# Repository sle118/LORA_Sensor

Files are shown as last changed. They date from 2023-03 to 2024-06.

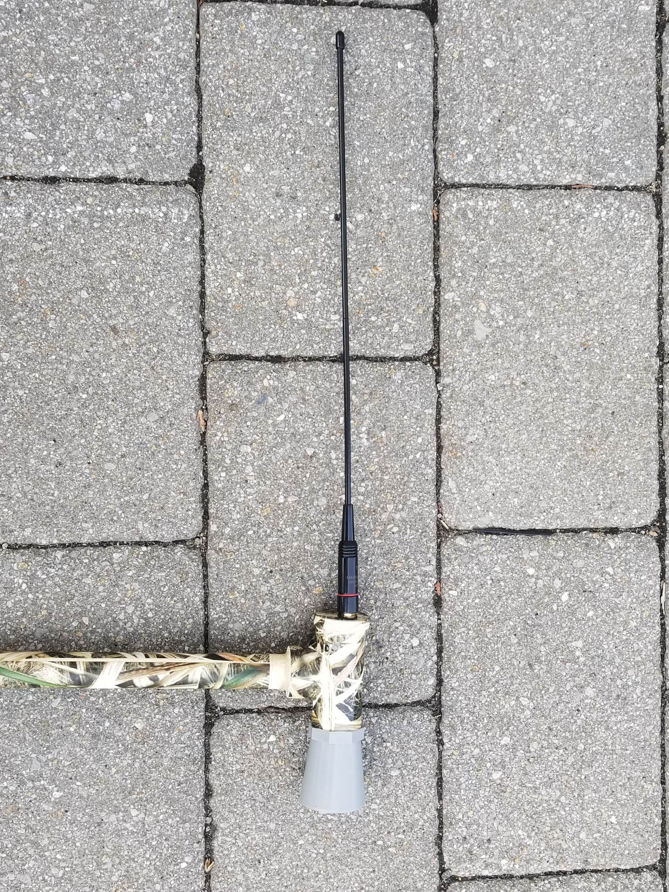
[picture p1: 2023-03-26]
LORA_sensor.jpg

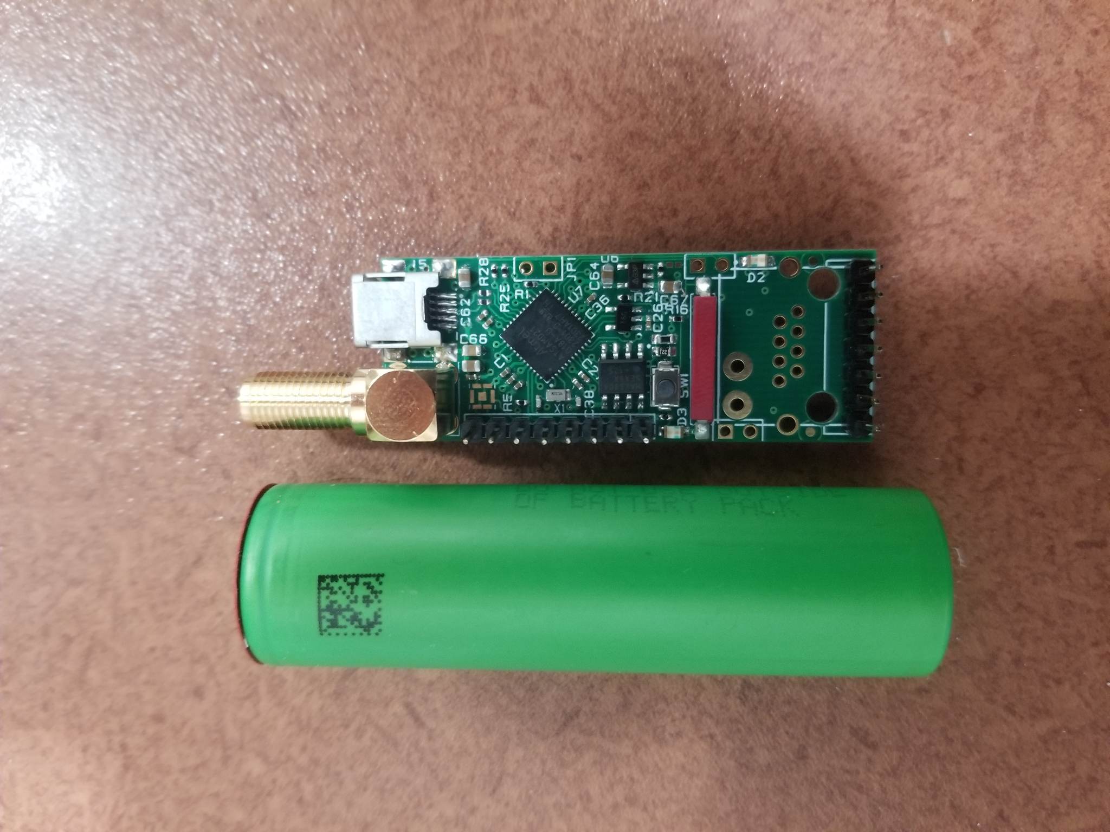
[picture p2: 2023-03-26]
transmitter/333065999_787963605601215_1816039696866618922_n.jpg

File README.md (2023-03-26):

river water level monitoring via long range wireless sensor (LORA) and send update every 15 minute

i made this project for monitor the river near my house that suject to some flooding
sensor is desin to be small and fit inside PVC "T" and have long battery live
 great versatility and hackability

1-)based arond SAMD21G17 CPU and arduino commpatible

2-)long range LORA FCC certified radio module (up to 10KM)

3-)over 60 day on a singel 18650 3.6V litium cell (optional solar charger)

4-)mesure up to 10meter whit 1cm accuracy or 5meter whit 1mm accuracy

5-)magetic reed switch for detection of ice covert melt

6-)barometric presure and temperature sensor

7-)provision for water level and temperature detection via sumerged sensor

8-)provision for turbidity sensor

9-)RS-485 for add custom sensor

10-)user programable GPIO

all this in 51.68 mm * 19.94 mm

main water level detection is via Maxbotic ultrasonic sensor or china clone

submerged water level is via LPS28DFW   1meter water = 9.78kPa or 1.42PSI

ice melt is via a simple rock on the ice the tie to a magnet via a fish line

when ice melt rock shink and pull the magmet so it trig the magmetic reed switch

a provision is made on the PCB for put sensor power OFF when magnet is present for keep battery live over the winter

solar charger is in developmemt and come soon

same for turbidity sensor , by use of low-cost dish-washer sensor

receiver side is adafruit Adafruit Feather 32u4 RFM95 LoRa Radio- 868 or 915 MHz
combined to Adafruit Feather HUZZAH with ESP8266 
both board is stacked whit GND and USB pin connected togeter
TX pin of Feather 32u4 go to RX pin of Feather HUZZAH

server side is plain web service hosting whit a FTP server  ,create a dedicated FTP accont on a WWW accesible folder  and copy the .php file to it

live exemple :

http://www.alphatronique.com/lora_sensor/mesure.php    <- real time sensor value

http://www.alphatronique.com/lora_sensor/donnes.txt    <- sensor data history

have copmlet assembled and tested PCB aviable please contack me via www.alphatronique.com

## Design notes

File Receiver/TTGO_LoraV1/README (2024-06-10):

# LoRa Receiver Arduino Project

This project implements a LoRa receiver using an ESP32 module to receive data from a LoRa transmitter and log it to a Google Spreadsheet via a deployed Google Apps Script web app. The code uses a combination of libraries and custom configurations to manage the network connection and data processing.

## Prerequisites

- **Arduino IDE**: Ensure you have the latest version of Arduino IDE installed.
- **ESP32 Board Package**: Install the ESP32 board package in the Arduino IDE (via Board Manager), using version 2.x.x. If your receiver board has a 40MHz crystal, then only you can use V3.x.x.
- **Libraries**: The following libraries need to be installed from the Arduino Library Manager:
  - `Adafruit_GFX` by Adafruit
  - `Adafruit_SSD1306` by Adafruit
  - `ArduinoJson` by Benoit Blanchon
  - `RadioHead` by Mike McCauley - as of writing this, only the ESP32 board V2.x.x is supported
  - `WiFiManager` by tzapu
  - `LoRa Serialization` by Joscha Feth 

## Folder Structure

Ensure that the folder structure from the GitHub repository is preserved as the project uses common definitions and configuration header files (`Definitions.h`, `Configuration.h`) shared between the transmitter and receiver. This is crucial for aligning data and radio correctly across both the transmitter and receiver.

### Setting Up Symbolic Links

If the symlinks are not already set up or are not properly propagated after cloning the repository, follow these steps to create them manually from the root of the project:

#### For Windows:
1. Open Command Prompt as Administrator.
2. Navigate to the root of the project (where you cloned the repository).
3. Execute the following commands:
    ```sh
    mklink Receiver\TTGO_LoraV1\Definitions.h transmitter\Sensor_firmware\Feather9x_TX\Definitions.h
    mklink Receiver\TTGO_LoraV1\Configuration.h transmitter\Sensor_firmware\Feather9x_TX\Configuration.h
    ```

#### For Linux or macOS:
1. Open Terminal.
2. Navigate to the root of the project (where you cloned the repository).
3. Execute the following commands:
    ```sh
    ln -s ../transmitter/Sensor_firmware/Feather9x_TX/Definitions.h Receiver/TTGO_LoraV1/Definitions.h
    ln -s ../transmitter/Sensor_firmware/Feather9x_TX/Configuration.h Receiver/TTGO_LoraV1/Configuration.h
    ```

Ensure that these commands are executed at the project root level to correctly set up the paths.

## Configuration

Before compiling and uploading the firmware to your ESP32 device, update the following parameters in the code to match your setup:

- **Google Script Deployment ID** and **Document ID**: These can be obtained from the setup of the Google Apps Script linked to your Google Spreadsheet as described in the Google Apps Script README (`GoogleScript/README`).
- **WiFi Credentials**: Set up initially via the WiFiManager portal that pops up automatically when no WiFi connection can be established.
- **LoRa Configuration**: Ensure the frequency and mode match those of your LoRa transmitter by reviewing header file `transmitter/Sendor_firmware/Feather9x_TX/Configuration.h`.

### Updating Certificates

In case the root certificate for `script.google.com` expires or needs updating, follow these steps:
1. In Chrome, navigate to `script.google.com`.
2. Click on the padlock icon in the address bar, then click on `Certificate`.
3. Navigate to the `Details` tab and export the certificate.
4. Replace the existing certificate in your Arduino code with the new one and/or activate the portal (see below) and update the certificate from the configuration page.

### Manual Control Over WiFi Configuration Portal

The WiFi configuration portal can be manually triggered by pressing the "PRG" button on the ESP32 board (mapped to GPIO0). This allows for on-demand reconfiguration of network settings.

## Compiling and Uploading

1. Open the Arduino IDE and select the `ESP32 Dev Module` as your board.
2. Set the serial port to the one that corresponds to your ESP32 module.
3. Adjust the `SERIAL_CONSOLE_SPEED` if necessary to match your debugging preference.
4. Compile and upload the code to your ESP32.

## Operation

Once deployed, the ESP32 will listen for LoRa transmissions and log received data to your specified Google Spreadsheet. The code also uses the display to show live data and transmit status. Ensure your LoRa transmitter is operational and configured to send data at the expected frequency and settings.

## License

MIT License

Copyright (c) 2024 Sebastien Leclerc

Permission is hereby granted, free of charge, to any person obtaining a copy
of this software and associated documentation files (the "Software"), to deal
in the Software without restriction, including without limitation the rights
to use, copy, modify, merge, publish, distribute, sublicense, and/or sell
copies of the Software, and to permit persons to whom the Software is
furnished to do so, subject to the following conditions:

The above copyright notice and this permission notice shall be included in all
copies or substantial portions of the Software.

THE SOFTWARE IS PROVIDED "AS IS", WITHOUT WARRANTY OF ANY KIND, EXPRESS OR
IMPLIED, INCLUDING BUT NOT LIMITED TO THE WARRANTIES OF MERCHANTABILITY,
FITNESS FOR A PARTICULAR PURPOSE AND NONINFRINGEMENT. IN NO EVENT SHALL THE
AUTHORS OR COPYRIGHT HOLDERS BE LIABLE FOR ANY CLAIM, DAMAGES OR OTHER
LIABILITY, WHETHER IN AN ACTION OF CONTRACT, TORT OR OTHERWISE, ARISING FROM,
OUT OF OR IN CONNECTION WITH THE SOFTWARE OR THE USE OR OTHER DEALINGS IN THE
SOFTWARE.

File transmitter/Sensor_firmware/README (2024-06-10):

# LoRa Sensor Arduino Project Setup

This guide provides detailed instructions on how to configure your Arduino environment to use custom board definitions necessary for the LoRa Sensor project, particularly for the `Alphatronique LoRa Sensor (SAMD21)` board, which is compatible with the Adafruit Feather M0.

## Prerequisites

- Arduino IDE installed on your computer.
- Access to the GitHub repository where the project is hosted.

## Custom Board Definitions

The project uses specific hardware definitions that are not included in the standard Arduino IDE. These definitions are crucial for compiling the transmitter sketch correctly.

### Steps to Install Custom Hardware Definitions

1. **Clone the Repository:**
   Start by cloning the LoRa_Sensor repository to your local machine. Ensure you have Git installed or download the ZIP file directly from GitHub.

    ```bash
    git clone https://github.com/yourusername/LoRa_Sensor.git
    ```

2. **Locate the Hardware Definitions:**
   Navigate to the `transmitter/Sensor_firmware` directory within the cloned repository. Here, you will find a folder named `hardware` containing the board definitions for `Alphatronique LoRa Sensor (SAMD21)`.

3. **Copy the Hardware Folder:**
   You need to copy this `hardware` folder into your Arduino directory where additional board definitions are stored.

    ### For Windows:
    Copy the `hardware` folder to the following location:

    ```plaintext
    C:\Users\<YourUsername>\Documents\Arduino\hardware
    ```

    If the `hardware` folder does not exist, create it.

    ### For macOS and Linux:
    Copy the `hardware` folder to:

    ```plaintext
    ~/Documents/Arduino/hardware
    ```

    If the `hardware` folder does not exist, create it.

4. **Restart Arduino IDE:**
   Close and reopen your Arduino IDE after copying the files. This will prompt the IDE to reload all available board definitions.

5. **Select the Custom Board:**
   Go to `Tools > Board` in the Arduino IDE, and you should now see `Alphatronique LoRa Sensor (SAMD21)` listed under the custom boards. Select this board for compiling the transmitter sketch.

## Compiling and Uploading the Sketch

Once the board definitions are set up, open the transmitter sketch from the `LoRa_Sensor` project and verify/update any necessary configurations specific to your setup. Compile and upload the sketch to your Alphatronique LoRa Sensor board.

## Troubleshooting

If you encounter issues with the Arduino IDE not recognizing the custom board, ensure the `hardware` folder is correctly placed and contains all required files. Sometimes, a second restart of the Arduino IDE or a reinstallation of the Arduino IDE might be necessary.

## License

MIT License

Copyright (c) 2024 Sebastien Leclerc

Permission is hereby granted, free of charge, to any person obtaining a copy
of this software and associated documentation files (the "Software"), to deal
in the Software without restriction, including without limitation the rights
to use, copy, modify, merge, publish, distribute, sublicense, and/or sell
copies of the Software, and to permit persons to whom the Software is
furnished to do so, subject to the following conditions:

The above copyright notice and this permission notice shall be included in all
copies or substantial portions of the Software.

THE SOFTWARE IS PROVIDED "AS IS", WITHOUT WARRANTY OF ANY KIND, EXPRESS OR
IMPLIED, INCLUDING BUT NOT LIMITED TO THE WARRANTIES OF MERCHANTABILITY,
FITNESS FOR A PARTICULAR PURPOSE AND NONINFRINGEMENT. IN NO EVENT SHALL THE
AUTHORS OR COPYRIGHT HOLDERS BE LIABLE FOR ANY CLAIM, DAMAGES OR OTHER
LIABILITY, WHETHER IN AN ACTION OF CONTRACT, TORT OR OTHERWISE, ARISING FROM,
OUT OF OR IN CONNECTION WITH THE SOFTWARE OR THE USE OR OTHER DEALINGS IN THE
SOFTWARE.

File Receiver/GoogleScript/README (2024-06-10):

# Google Sheets Logging Script

This guide explains how to create a Google Spreadsheet and attach a Google Apps Script to it, enabling data logging via HTTP GET requests as implemented in the TTGO_Lora Arduino project. The script will log data to specified sheets and handle different commands.

## Prerequisites

- A Google account
- Basic understanding of Google Sheets
- Familiarity with Google Apps Script

## Steps to Create and Deploy the Google Apps Script

### 1. Create a Google Spreadsheet

1. Open [Google Sheets](https://sheets.google.com) and create a new spreadsheet.
2. Name your spreadsheet (e.g., `Data Logger`).

### 2. Open the Script Editor

1. In your new spreadsheet, click on `Extensions` in the menu.
2. Select `Apps Script`.

### 3. Add the Google Apps Script

1. Delete any code in the script editor and paste the provided script.

### 4. Save and Deploy the Script

1. Click on the `File` menu and select `Save`. Name your project (e.g., `DataLoggerScript`).
2. Click on the `Deploy` button and select `New deployment`.
3. Choose `Web app` as the deployment type.
4. Set `Execute as` to `Me (your email)`.
5. Set `Who has access` to `Anyone` or `Anyone, even anonymous` depending on your needs.
6. Click on `Deploy`.
7. Copy the deployment ID provided after the deployment. This will be used to build the endpoint URL to which you will send your GET requests.

### 5. Test the Script (Optional)

1. Open a new browser tab and navigate to the deployment URL.
2. Append query parameters to the URL to test data logging. For example:

    ```
    https://script.google.com/macros/s/<your-deployment-id>/exec?sheet_name=data&bat_voltage=3.7&rawVbat=3700&distance=5.0&duration=120&temperature=22.5&internal_temp=22.5&internal_voltage=3.3&core_voltage=3.3&packetnum=1&snr=10&uuid=1234&command=append_row
    ```

3. Check your Google Sheet to verify that the data has been logged correctly.

## Summary

By following these steps, you've created a Google Apps Script that logs data to a Google Spreadsheet via HTTP GET requests. You can customize the script further to handle different types of data and commands as needed.

## License

MIT License

Copyright (c) 2024 Sebastien Leclerc

Permission is hereby granted, free of charge, to any person obtaining a copy
of this software and associated documentation files (the "Software"), to deal
in the Software without restriction, including without limitation the rights
to use, copy, modify, merge, publish, distribute, sublicense, and/or sell
copies of the Software, and to permit persons to whom the Software is
furnished to do so, subject to the following conditions:

The above copyright notice and this permission notice shall be included in all
copies or substantial portions of the Software.

THE SOFTWARE IS PROVIDED "AS IS", WITHOUT WARRANTY OF ANY KIND, EXPRESS OR
IMPLIED, INCLUDING BUT NOT LIMITED TO THE WARRANTIES OF MERCHANTABILITY,
FITNESS FOR A PARTICULAR PURPOSE AND NONINFRINGEMENT. IN NO EVENT SHALL THE
AUTHORS OR COPYRIGHT HOLDERS BE LIABLE FOR ANY CLAIM, DAMAGES OR OTHER
LIABILITY, WHETHER IN AN ACTION OF CONTRACT, TORT OR OTHERWISE, ARISING FROM,
OUT OF OR IN CONNECTION WITH THE SOFTWARE OR THE USE OR OTHER DEALINGS IN THE
SOFTWARE.

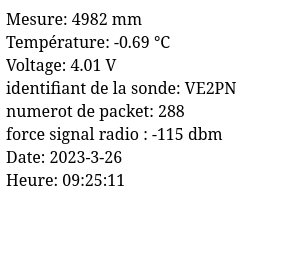
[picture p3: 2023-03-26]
server_screen_shot.png

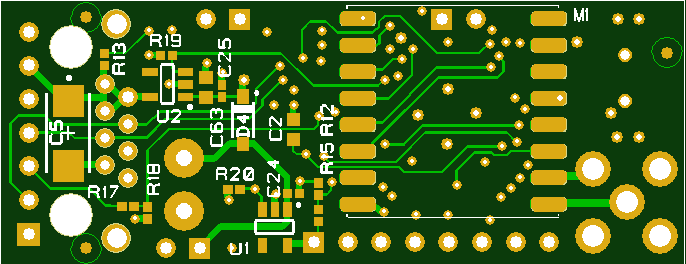
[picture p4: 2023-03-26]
transmitter/PCB/lora_v1_bot.png

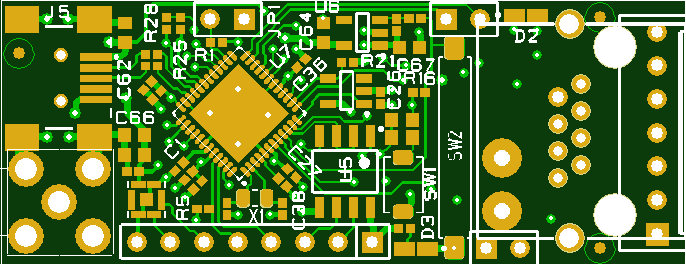
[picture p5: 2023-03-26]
transmitter/PCB/lora_v1_top.png

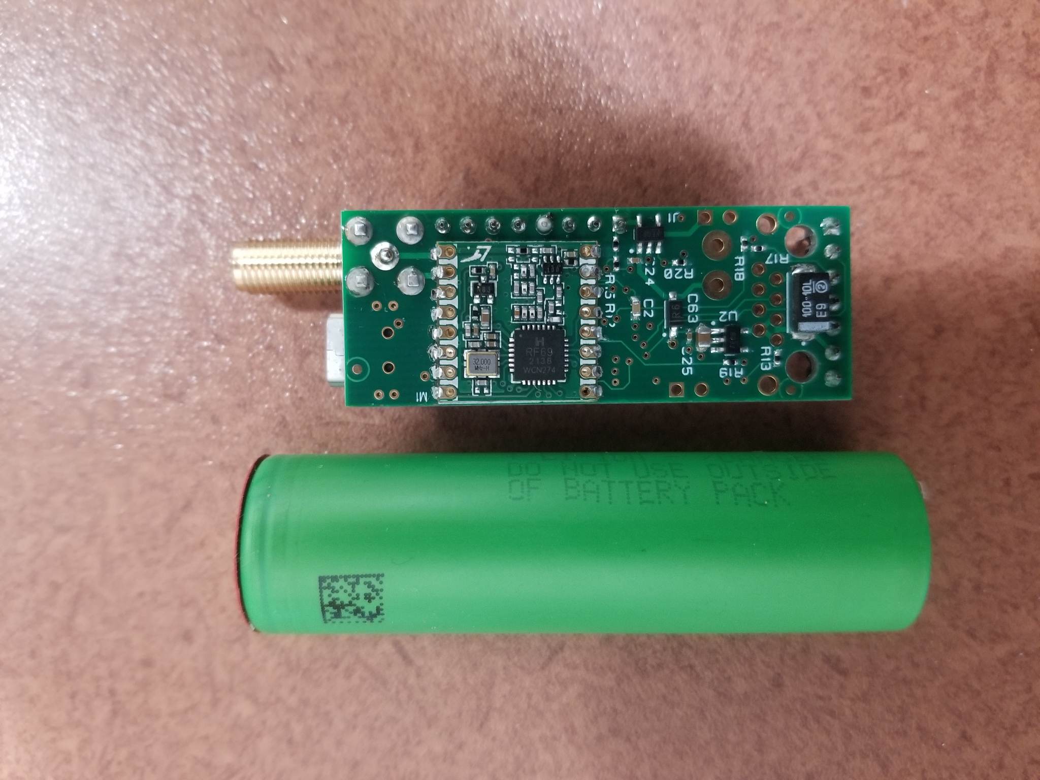
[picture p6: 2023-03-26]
transmitter/333066020_973101613681641_4937073247365786062_n.jpg

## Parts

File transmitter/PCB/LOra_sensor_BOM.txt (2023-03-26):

BOM for current Variant
Variant Name: Variant Description: Name  Part No       Description
----------------------------------------
C25   C1005X7R1H104K050BB            CAP CER 0.1UF 50V X7R 0402 
C24   C1005X7R1H104K050BB            CAP CER 0.1UF 50V X7R 0402 
R15   RC0402FR-07100KL               RES SMD 100K OHM 1/16W 5% 0404 
FI6   FIDUCIAL                        
FI5   FIDUCIAL                        
U9    TMP36-SOT                      SENSOR TEMP RATIOMETRIC SOT23-5 
FI4   FIDUCIAL                        
J6    CON2_1X2                       CONN RECEPT 2POS .100 VERT DUAL 
C28   C1005X7R1H104K050BB            CAP CER 0.1UF 50V X7R 0402 
FI2   FIDUCIAL                        
PAD4  PCB-PAD                         
U6    AP2112K-3.3T                   600MA LDO REGULATOR WHIT ENABLE 
U5    ADM4851ARZ                     IC TXRX RS-485422 500KBPS 8-SOIC 
U7    ATSAMD21G18A-MUT               IC MCU 32BIT 256K FLASH 48QFN 
C26   C1005X7R1H104K050BB            CAP CER 0.1UF 50V X7R 0402 
R12   RC0402FR-07100KL               RES SMD 100K OHM 1/16W 5% 0404 
J3    0438600013                     CONN MOD JACK 8P8C R/A SHIELDED 
R28   RC0402FR-072KL                 RES SMD 2K OHM 1% 1/16W 0402 
D3    LED                            LED GREEN CLEAR 0805 SMD 
C64   GRM188R61A106KE69D             CAP CER 10UF 10V X5R 0603 
C63   GRM188R61A106KE69D             CAP CER 10UF 10V X5R 0603 
C29   C1005X7R1H104K050BB            CAP CER 0.1UF 50V X7R 0402 
C62   GRM188R61A106KE69D             CAP CER 10UF 10V X5R 0603 
JP1   JUMPER                          
R21   RC0402FR-07100KL               RES SMD 100K OHM 1/16W 5% 0404 
R27   RC0402FR-072KL                 RES SMD 2K OHM 1% 1/16W 0402 
C66   GRM188R61A106KE69D             CAP CER 10UF 10V X5R 0603 
R18   RC0402FR-07100KL               RES SMD 100K OHM 1/16W 5% 0404 
CN1   RF_SMA                         CONN SMA JACK R/A 50 OHM PCB 
U1    MIC2004                        IC DISTRIBUTION SW 0.5A SOT23-5 
C1    GRM155R70J105KA12D             CAP CER 1UF 6.3V X7R 0402 
C3    GRM155R70J105KA12D             CAP CER 1UF 6.3V X7R 0402 
C39   500R07S220JV4T                 CAP CER 22PF 50V C0G/NP0 0402 
FI1   FIDUCIAL                        
FI3   FIDUCIAL                        
J5    USB_MINI_B                     CONN RECEPT MINI USB2.0 5POS 
R16   RC0402FR-07100KL               RES SMD 100K OHM 1/16W 5% 0404 
C38   500R07S220JV4T                 CAP CER 22PF 50V C0G/NP0 0402 
M1    RFM69HCW                       ISM LORA MODULE 
C4    GRM155R70J105KA12D             CAP CER 1UF 6.3V X7R 0402 
R19   RC0402FR-07100KL               RES SMD 100K OHM 1/16W 5% 0404 
R20   RC0402FR-07100KL               RES SMD 100K OHM 1/16W 5% 0404 
X1    CM8V-T1A                       CRYSTAL 32.768KHZ 
R1    RC0402FR-07100KL               RES SMD 100K OHM 1/16W 5% 0404 
SW1   CS1213AG                       SW SMT 0805 
J2    CON2_1X2                       CONN RECEPT 2POS .100 VERT DUAL 
R3    RC0603FR-071KL                 RES SMD 1K OHM 1% 1/10W 0603 
D4    MBR0560                        DIODE SCHOTTKY 60V 500MA SOD123 
R24   RC0402FR-0722RL                RES SMD 22 OHM 1% 1/16W 0402 
C30   C1005X7R1H104K050BB            CAP CER 0.1UF 50V X7R 0402 
R26   RC0402FR-070RL                 RES SMD 0 OHM JUMPER 1/16W 0402 
C67   GRM188R61A106KE69D             CAP CER 10UF 10V X5R 0603 
U2    MIC2004                        IC DISTRIBUTION SW 0.5A SOT23-5 
C5    CT107C10K                      CAP TANT 100UF 10V 10% 2312 
C23   C1005X7R1H104K050BB            CAP CER 0.1UF 50V X7R 0402 
D2    LED                            LED GREEN CLEAR 0805 SMD 
J4    CON8_1X8UA                      
R2    RC0402FR-07100KL               RES SMD 100K OHM 1/16W 5% 0404 
PAD3  PCB-PAD                         
SW2   CT10-1030-G4                   SWITCH REED SPST-NO 
C65   GRM188R61A106KE69D             CAP CER 10UF 10V X5R 0603 
R5    RC0402FR-071KL                 RES SMD 1K OHM 1% 1/16W 0402 
R17   RC0402FR-07100KL               RES SMD 100K OHM 1/16W 5% 0404 
R25   RC0402FR-0722RL                RES SMD 22 OHM 1% 1/16W 0402 
R4    RC0603FR-07270RL               RES SMD 270 OHM 1% 1/10W 0603 
R13   RC0402FR-071KL                 RES SMD 1K OHM 1% 1/16W 0402 
C6    CT107C10K                      CAP TANT 100UF 10V 10% 2312 
C36   C1005X7R1H104K050BB            CAP CER 0.1UF 50V X7R 0402 
C2    GRM188R71H104KA93D             CAP CER 0.1UF 50V 5% X7R 0603 
R14   RC0402FR-071KL                 RES SMD 1K OHM 1% 1/16W 0402 
U3    LPS28DFW                       DUAL ADSOLUTE PSI SENSIR 
C27   C1005X7R1H104K050BB            CAP CER 0.1UF 50V X7R 0402 
J1    MTA_100_7                      CONN HEADER VERT 7POS .100 TIN

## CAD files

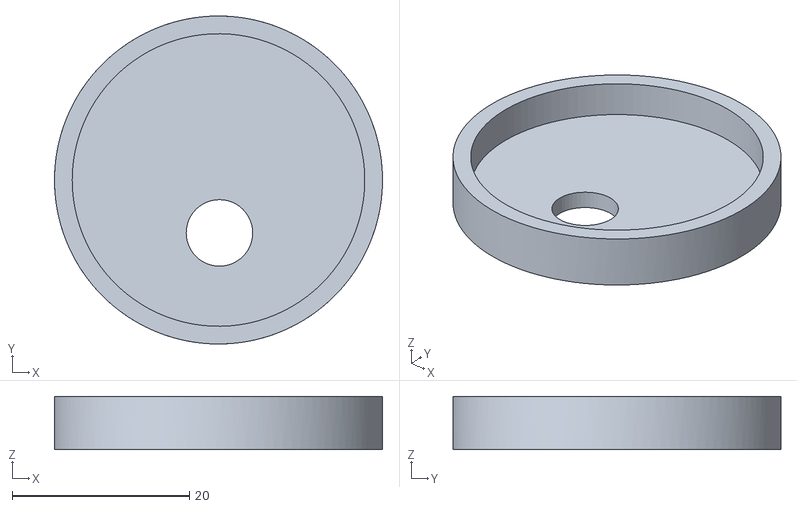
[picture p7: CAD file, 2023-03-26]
transmitter/cap v1.1.stl
37.0 x 37.0 x 6.00

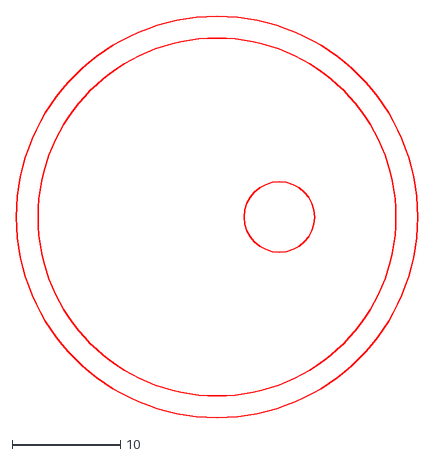
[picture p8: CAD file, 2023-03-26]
transmitter/cap.DXF
37.0 x 37.0

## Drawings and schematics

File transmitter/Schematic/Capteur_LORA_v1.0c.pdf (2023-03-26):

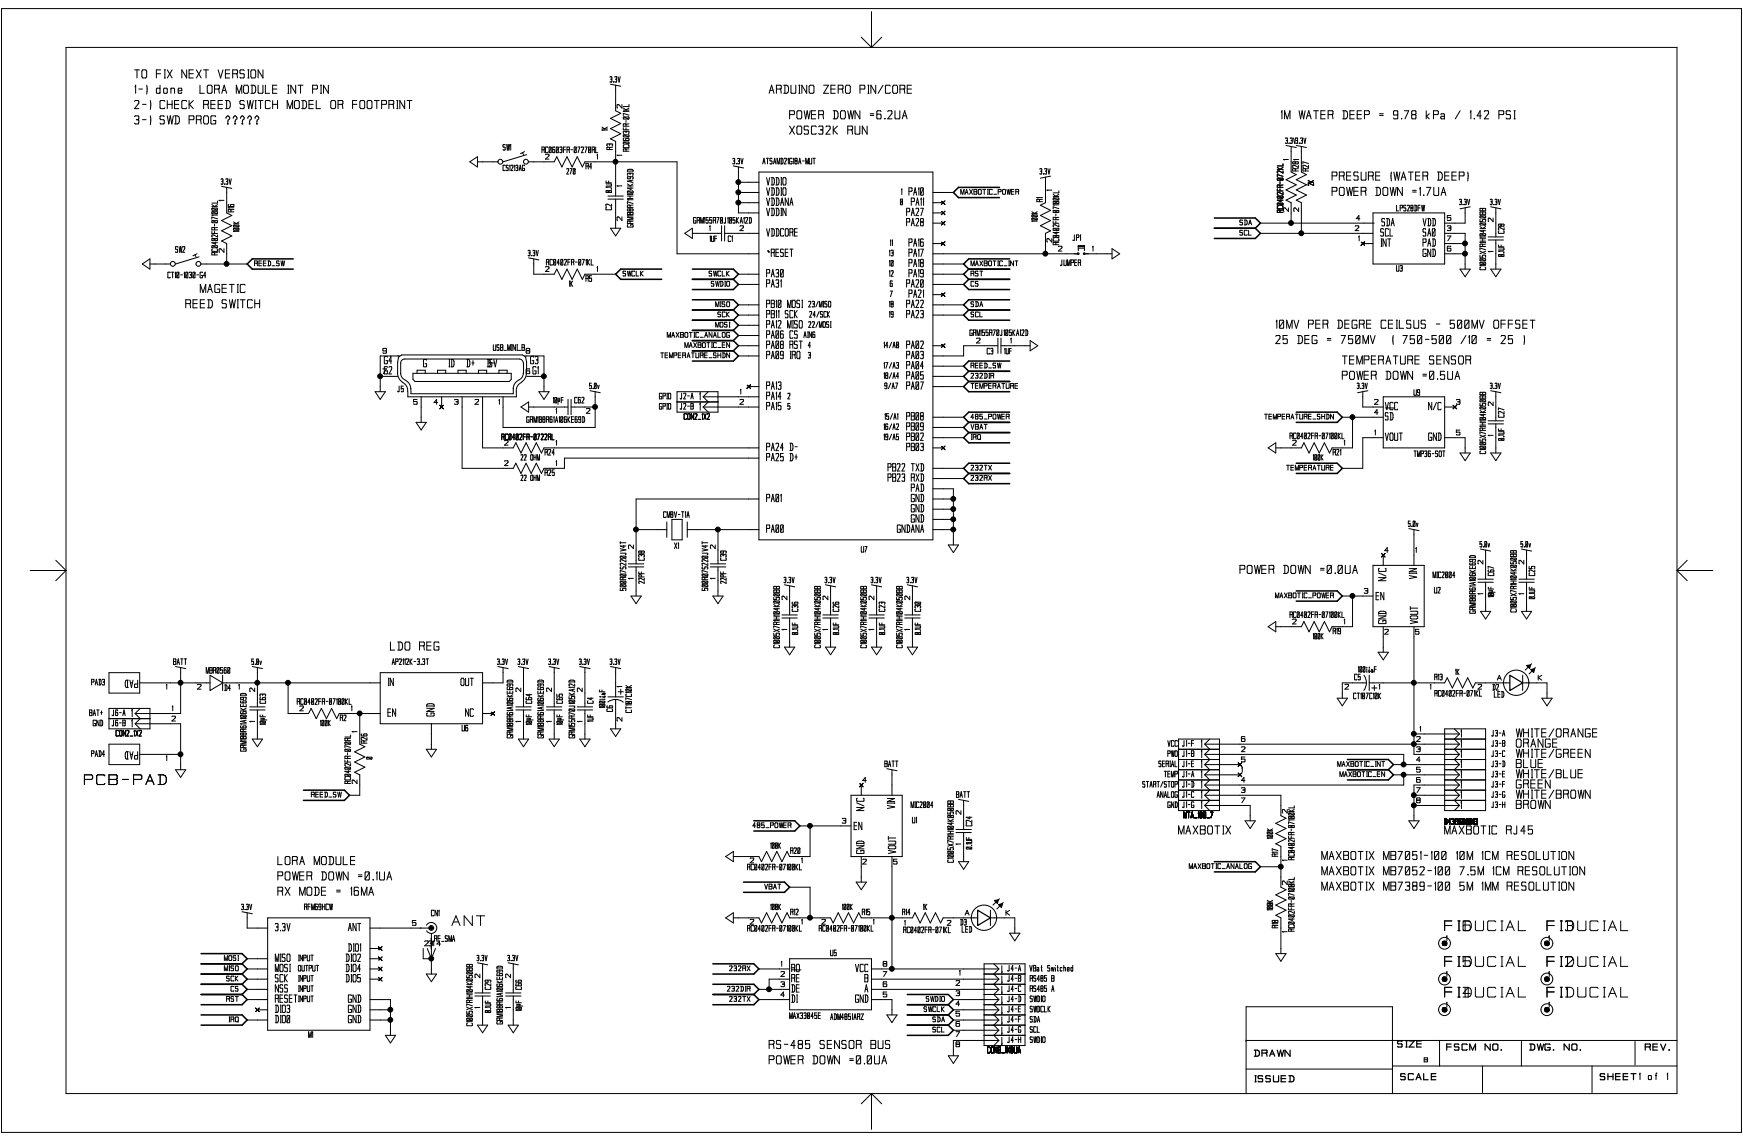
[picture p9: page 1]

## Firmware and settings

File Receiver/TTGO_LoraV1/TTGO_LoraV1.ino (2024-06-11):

/***
 * MIT License
 * 
 * Copyright (c) 2024 Sebastien Leclerc
 * 
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
 * THE SOFTWARE IS PROVIDED "AS IS", WITHOUT WARRANTY OF ANY KIND, EXPRESS OR
 * IMPLIED, INCLUDING BUT NOT LIMITED TO THE WARRANTIES OF MERCHANTABILITY,
 * FITNESS FOR A PARTICULAR PURPOSE AND NONINFRINGEMENT. IN NO EVENT SHALL THE
 * AUTHORS OR COPYRIGHT HOLDERS BE LIABLE FOR ANY CLAIM, DAMAGES OR OTHER
 * LIABILITY, WHETHER IN AN ACTION OF CONTRACT, TORT OR OTHERWISE, ARISING FROM,
 * OUT OF OR IN CONNECTION WITH THE SOFTWARE OR THE USE OR OTHER DEALINGS IN THE
 * SOFTWARE.
 ***/

/***
 *
 * Loosely inspired by other people's efforts, like the one below: 
 * https://github.com/StorageB/Google-Sheets-Logging/tree/master?tab=readme-ov-file
 *
 * At the time of writing this code, it was difficult to get the ESP32 ssl/tls stack
 * to reliably POST a request to the google scripts app, so instead the code is 
 * using a GET request with parameters passed in the URL.
 *
 * The base configuration is intended to be used with a TTGO Lora32 V1 board with
 * the corresponding PIN definitions. 
 *
 ***/

/**
 * The below includes are used to align radio information between the transmitter and
 * receivers as well as to define a common data structure to be exchanged between the two
 * for measurements.
 *
 * #include <Definitions.h>
 * #include <Configuration.h>
 *
 * These files reside in a different part of the project directory and must be made accessible
 * to this sketch. To achieve this, we use symbolic links (symlinks). If the symlinks are not
 * already set up or are not properly propagated after cloning the repository, follow these
 * steps to create them manually from the root of the project:
 *
 * For Windows:
 * 1. Open Command Prompt as Administrator.
 * 2. Navigate to the root of the project (where you cloned the repository).
 * 3. Execute the following commands:
 *    mklink Receiver\TTGO_LoraV1\Definitions.h transmitter\Sensor_firmware\Feather9x_TX\Definitions.h
 *    mklink Receiver\TTGO_LoraV1\Configuration.h transmitter\Sensor_firmware\Feather9x_TX\Configuration.h
 *
 * For Linux or macOS:
 * 1. Open Terminal.
 * 2. Navigate to the root of the project (where you cloned the repository).
 * 3. Execute the following commands:
 *    ln -s ../transmitter/Sensor_firmware/Feather9x_TX/Definitions.h Receiver/TTGO_LoraV1/Definitions.h
 *    ln -s ../transmitter/Sensor_firmware/Feather9x_TX/Configuration.h Receiver/TTGO_LoraV1/Configuration.h
 *
 * Ensure that these commands are executed at the project root level to correctly set up the paths.
 */


/**************************
 *
 * WARNING:
 * For the TTGO Lora-V1 Oled board, you HAVE to stick to the esp32 boards with version 2.x.x as version 3.x.x
 * dropped support for boards with a 26MHz crystal. Without proper support, wifi will NOT work as the 
 * system clock configuration will assume a frequency of 40MHz during build.
 *
 **************************/
 


#define WM_DEBUG_LEVEL WM_DEBUG_VERBOSE
#include <Adafruit_GFX.h>
#include <Adafruit_SSD1306.h>
#include <Arduino.h>
#include <ArduinoJson.h>
#include <RH_RF95.h>
#include <SPI.h>
#include <SPIFFS.h>
#include <WiFi.h>
#include <HTTPClient.h>
#include <WiFiManager.h>
#include <Wire.h>
#include "Definitions.h"
#include "Configuration.h"
#if defined(ESP_ARDUINO_VERSION) && (ESP_ARDUINO_VERSION >= ESP_ARDUINO_VERSION_VAL(3, 0, 0))
#include <NetworkClientSecure.h>
#else
#include <WiFiClientSecure.h>
#endif
#include <LoraEncoder.h>

JsonDocument json;
#define SERIAL_CONSOLE_SPEED 115200

// Constants for configuring the OLED display
#define OLED_SDA 4
#define OLED_SCL 15
#define OLED_RST 16
#define SCREEN_WIDTH 128
#define SCREEN_HEIGHT 64
#define SCREEN_ADDRESS 0x3C  // 0x3D for 128x64, 0x3C for 128x32

// Constants for LoRa module
#define RFM95_CS 18
#define RFM95_RST 14
#define RFM95_INT 26
#define SX1278_MISO 19
#define SX1278_MOSI 27
#define SX1278_SCLK 5
#define SX1278_CS 18
#define SX1278_DIO 26
#define SX1278_RST 14

#define LED 13  // Blinky on receipt

// Debounce and portal control
#define TRIGGER_PIN 0
const unsigned long debounceDelay = 50;
const unsigned long minInterval = 5000;
const char * apPassword = "loragateway";

// Default certificate for NetworkClientSecure/WifiClientSecure
const char* root_ca = R"EOF(
-----BEGIN CERTIFICATE-----
MIIFVzCCAz+gAwIBAgINAgPlk28xsBNJiGuiFzANBgkqhkiG9w0BAQwFADBHMQsw
CQYDVQQGEwJVUzEiMCAGA1UEChMZR29vZ2xlIFRydXN0IFNlcnZpY2VzIExMQzEU
MBIGA1UEAxMLR1RTIFJvb3QgUjEwHhcNMTYwNjIyMDAwMDAwWhcNMzYwNjIyMDAw
MDAwWjBHMQswCQYDVQQGEwJVUzEiMCAGA1UEChMZR29vZ2xlIFRydXN0IFNlcnZp
Y2VzIExMQzEUMBIGA1UEAxMLR1RTIFJvb3QgUjEwggIiMA0GCSqGSIb3DQEBAQUA
A4ICDwAwggIKAoICAQC2EQKLHuOhd5s73L+UPreVp0A8of2C+X0yBoJx9vaMf/vo
27xqLpeXo4xL+Sv2sfnOhB2x+cWX3u+58qPpvBKJXqeqUqv4IyfLpLGcY9vXmX7w
Cl7raKb0xlpHDU0QM+NOsROjyBhsS+z8CZDfnWQpJSMHobTSPS5g4M/SCYe7zUjw
TcLCeoiKu7rPWRnWr4+wB7CeMfGCwcDfLqZtbBkOtdh+JhpFAz2weaSUKK0Pfybl
qAj+lug8aJRT7oM6iCsVlgmy4HqMLnXWnOunVmSPlk9orj2XwoSPwLxAwAtcvfaH
szVsrBhQf4TgTM2S0yDpM7xSma8ytSmzJSq0SPly4cpk9+aCEI3oncKKiPo4Zor8
Y/kB+Xj9e1x3+naH+uzfsQ55lVe0vSbv1gHR6xYKu44LtcXFilWr06zqkUspzBmk
MiVOKvFlRNACzqrOSbTqn3yDsEB750Orp2yjj32JgfpMpf/VjsPOS+C12LOORc92
wO1AK/1TD7Cn1TsNsYqiA94xrcx36m97PtbfkSIS5r762DL8EGMUUXLeXdYWk70p
aDPvOmbsB4om3xPXV2V4J95eSRQAogB/mqghtqmxlbCluQ0WEdrHbEg8QOB+DVrN
VjzRlwW5y0vtOUucxD/SVRNuJLDWcfr0wbrM7Rv1/oFB2ACYPTrIrnqYNxgFlQID
AQABo0IwQDAOBgNVHQ8BAf8EBAMCAYYwDwYDVR0TAQH/BAUwAwEB/zAdBgNVHQ4E
FgQU5K8rJnEaK0gnhS9SZizv8IkTcT4wDQYJKoZIhvcNAQEMBQADggIBAJ+qQibb
C5u+/x6Wki4+omVKapi6Ist9wTrYggoGxval3sBOh2Z5ofmmWJyq+bXmYOfg6LEe
QkEzCzc9zolwFcq1JKjPa7XSQCGYzyI0zzvFIoTgxQ6KfF2I5DUkzps+GlQebtuy
h6f88/qBVRRiClmpIgUxPoLW7ttXNLwzldMXG+gnoot7TiYaelpkttGsN/H9oPM4
7HLwEXWdyzRSjeZ2axfG34arJ45JK3VmgRAhpuo+9K4l/3wV3s6MJT/KYnAK9y8J
ZgfIPxz88NtFMN9iiMG1D53Dn0reWVlHxYciNuaCp+0KueIHoI17eko8cdLiA6Ef
MgfdG+RCzgwARWGAtQsgWSl4vflVy2PFPEz0tv/bal8xa5meLMFrUKTX5hgUvYU/
Z6tGn6D/Qqc6f1zLXbBwHSs09dR2CQzreExZBfMzQsNhFRAbd03OIozUhfJFfbdT
6u9AWpQKXCBfTkBdYiJ23//OYb2MI3jSNwLgjt7RETeJ9r/tSQdirpLsQBqvFAnZ
0E6yove+7u7Y/9waLd64NnHi/Hm3lCXRSHNboTXns5lndcEZOitHTtNCjv0xyBZm
2tIMPNuzjsmhDYAPexZ3FL//2wmUspO8IFgV6dtxQ/PeEMMA3KgqlbbC1j+Qa3bb
bP6MvPJwNQzcmRk13NfIRmPVNnGuV/u3gm3c
-----END CERTIFICATE-----
)EOF";
char cert_buffer[4096];  // Buffer large enough to hold the certificate
const char* custom_cert_html =
  "<br/><label for='certificate'>Root Certificate</label><textarea name='certificate' rows='10' cols='70'>%s</textarea>";

// Configuration parameters for Google Sheets integration
struct Config {
  String GScriptId;
  String SheetName = "distance";
  String DocumentID;
  String host = "script.google.com";
  String httpsPort = "443";
  String cert = root_ca;
  bool Changed = false;
} conf;

String LastPublish = "";
// Declarations
WiFiManager wifiManager;  // Global WiFiManager instance
Adafruit_SSD1306 display(SCREEN_WIDTH, SCREEN_HEIGHT, &Wire, OLED_RST);
RH_RF95 rf95(RFM95_CS, RFM95_INT);
uint8_t rx_buf[RH_RF95_MAX_MESSAGE_LEN];
uint8_t rx_len = sizeof(rx_buf);
unsigned long lastMessageReceived = 0;
int lastSNR = 0;
bool portalRunning = false;
unsigned long lastButtonPressTime = 0;
unsigned long lastDisplay = 0;


// Custom parameters for WiFiManager
WiFiManagerParameter custom_script_id(
  "gscript_id", "Google Script Deployment ID", conf.GScriptId.c_str(), 80);
WiFiManagerParameter custom_doc_id(
  "custom_doc_id", "Google Spreadsheet Document ID", conf.DocumentID.c_str(), 80);
WiFiManagerParameter custom_sheet_name("sheet_name", "Sheet name", conf.SheetName.c_str(), 40);
WiFiManagerParameter custom_host("host_name", "Host name", conf.host.c_str(), 40);
WiFiManagerParameter custom_port("port_number", "Service Port", conf.httpsPort.c_str(), 6);
WiFiManagerParameter custom_cert(cert_buffer);

// Forward declarations
void setupDisplay();
void setupConfig();
void setupWiFi();
void setupLoRa();
void printInitialDisplay();
void saveConfigIfNeeded();
void receiveLoRaMessages();
void updateDisplayIfNeeded();
void toggleWiFiPortal();
void updateCustomFields();
void saveConfigCallback();
void pushLogs(const String& message);
void displayMeasurements(measurements_t* measures, unsigned long lastMessageTime, int snr);
void checkButton();
String bytesToHexString(uint8_t* buf, unsigned int len);

/**
 * Initialize system components and services.
 */
void setup() {
  setCpuFrequencyMhz(240);
  Serial.begin(SERIAL_CONSOLE_SPEED);
  

  auto upto = millis()+2000;
  while(!Serial && millis()<upto){}
  Wire.setPins(OLED_SDA, OLED_SCL);
  pinMode(TRIGGER_PIN, INPUT);
  setupDisplay();
  setupConfig();
  setupWiFi();
  setupLoRa();
  printInitialDisplay();
}

/**
 * @brief The main loop where essential system functions are orchestrated.
 *
 * This function represents the core execution cycle of the firmware. It continuously processes WiFi
 * management tasks, checks the status of a system button, manages configuration saving, receives
 * messages from LoRa, and updates the display. It is designed to run indefinitely, handling both
 * regular tasks and event-driven operations to maintain the system's responsiveness and
 * functionality.
 *
 * Details of operations handled in the loop:
 * - `wifiManager.process()`: Handles WiFi events and manages network connectivity.
 * - `checkButton()`: Monitors for button presses to potentially toggle the WiFi configuration
 * portal.
 * - `saveConfigIfNeeded()`: Saves the current configuration to persistent storage if there have
 * been any changes.
 * - `receiveLoRaMessages()`: Checks for and processes incoming LoRa messages.
 * - `updateDisplayIfNeeded()`: Updates the OLED display if there are changes to display content.
 *
 * @note This function must be optimized to avoid long blocking operations as it impacts the
 * responsiveness of user interactions and system communications. Ensure that any function called
 * within this loop adheres to real-time constraints appropriate for your application's
 * requirements.
 *
 * Usage Example:
 *
 * The `loop` function is automatically called by the Arduino framework and should be implemented to
 * handle all periodic and event-driven tasks necessary for the application. Here it's used to
 * integrate several subsystems (WiFi, button interface, LoRa communication, display updates) into a
 * cohesive operation:
 *
 *     void setup() {
 *         // Initialization routines for WiFi, button, LoRa, display
 *     }
 *
 *     void loop() {
 *         // Core loop code here
 *     }
 */
void loop() {
  wifiManager.process();    // Handle WiFi connection management
  checkButton();            // Check for user input via the button
  saveConfigIfNeeded();     // Persist configuration changes if needed
  receiveLoRaMessages();    // Handle incoming LoRa communications
  updateDisplayIfNeeded();  // Update display content if there's new data
}

/**
 * @brief Checks the state of a system button and toggles the WiFi portal if necessary.
 *
 * This function reads the state of a button connected to the `TRIGGER_PIN`. If the button is
 * pressed (detected as LOW), it implements a debounce logic and checks the button state again after
 * a brief delay. If the button is still pressed after the delay, the function calculates if the
 * minimum interval since the last recognized press has elapsed to avoid rapid toggling. If this
 * interval has passed, it updates the timestamp and calls `toggleWiFiPortal` to change the state of
 * the WiFi configuration portal.
 *
 * @note The button should be wired to pull up to VCC normally and connect to GND when pressed,
 * ensuring `TRIGGER_PIN` reads LOW when pressed. The system should handle `minInterval` and
 * `debounceDelay` to optimize responsiveness and prevent bouncing issues.
 *
 * Usage Example:
 *
 *     pinMode(TRIGGER_PIN, INPUT);  // Set the button pin as input
 *     attachInterrupt(digitalPinToInterrupt(TRIGGER_PIN), checkButton, CHANGE);  // Attach an
 * interrupt to the button pin
 *
 * This configuration allows for responsive user interaction without blocking the main program
 * execution, as the check is performed efficiently on button press.
 */
void checkButton() {
  if (digitalRead(TRIGGER_PIN) == LOW) {
    delay(debounceDelay);  // Debounce by waiting for a fixed short delay
    if (digitalRead(TRIGGER_PIN) == LOW) {
      unsigned long currentTime = millis();  // Get the current time in milliseconds
      // Check if the required time has passed since the last button press
      if (currentTime - lastButtonPressTime >= minInterval) {
        lastButtonPressTime = currentTime;  // Update the last button press time
        toggleWiFiPortal();                 // Toggle the state of the WiFi portal
      }
    }
  }
}

/**
 * @brief Toggles the WiFi configuration portal on or off.
 *
 * This function checks the current state of the WiFi portal. If the portal is not running, it
 * starts the portal and sets the `portalRunning` flag to true. If the portal is already running, it
 * stops the portal and sets the `portalRunning` flag to false. This allows for dynamic control over
 * the WiFi configuration portal, facilitating user interaction for network configuration without
 * needing to restart the device.
 *
 * @note This function should be tied to a user-triggered event, such as pressing a button, to
 *       allow manual control over the WiFi configuration state.
 *
 * Usage Example:
 *
 * Typically, this function is bound to a physical button press:
 *
 *     pinMode(buttonPin, INPUT_PULLUP); // Setup button pin
 *     attachInterrupt(digitalPinToInterrupt(buttonPin), toggleWiFiPortal, FALLING);
 *
 * This setup allows users to open the configuration portal by pressing a button, enabling them
 * to connect the device to new networks or change WiFi settings.
 */
void toggleWiFiPortal() {
  if (!portalRunning) {
    Serial.println("Button Pressed, Starting Portal");
    updateCustomFields();          // Refresh custom fields to ensure current settings are displayed
    wifiManager.startWebPortal();  // Start the WiFi configuration portal
    portalRunning = true;          // Set flag to indicate the portal is running
  } else {
    Serial.println("Button Pressed, Stopping Portal");
    wifiManager.stopWebPortal();  // Stop the WiFi configuration portal
    portalRunning = false;        // Reset flag to indicate the portal is not running
  }
}

/**
 * @brief Displays current configuration settings to the serial output.
 *
 * This function prints the values of key configuration parameters including the Google Script ID,
 * sheet name, document ID, server host, HTTPS port, etc. It is useful for debugging
 * and verifying that configuration settings have been loaded and set correctly.
 *
 * @note This function outputs data to the serial monitor, which should be opened and set to the
 * correct baud rate to view the output.
 *
 * Usage Example:
 *
 * Call this function after configuration settings are loaded or updated to verify their values:
 *
 *     setupConfig();
 *     printContext();  // Verify the loaded configuration settings.
 */
void printContext() {
  Serial.println("Context data:");
  Serial.print("conf.GScriptId: ");
  Serial.println(conf.GScriptId);
  Serial.print("conf.SheetName: ");
  Serial.println(conf.SheetName);
  Serial.print("conf.DocumentID: ");
  Serial.println(conf.DocumentID);
  Serial.print("conf.host: ");
  Serial.println(conf.host);
  Serial.print("conf.httpsPort: ");
  Serial.println(conf.httpsPort);
  Serial.print("conf.cert: ");
  Serial.println(conf.cert);

}
/**
 * Retrieves a string value from a JSON document or returns a default if the key is not present or
 * the value is null.
 * @param doc The JSON document from which to extract the value.
 * @param key The key associated with the value to retrieve.
 * @param defaultValue The default value to return if the key is not found or the value is null.
 * @return The string value from the JSON document or the default value.
 */
String jsonValueOrDefault(
  const JsonDocument& doc, const char* key, const String& defaultValue = "") {
  Serial.printf("Checking if value exists for key=%s. ", key);
  if (doc.containsKey(key) && !doc[key].isNull()) {
    Serial.printf("Existing value = %s", doc[key].as<String>().c_str());
    return doc[key].as<String>();
  } else {
    Serial.printf("Default value = %s", defaultValue.c_str());
    return defaultValue;
  }
}

/**
 * @brief Initializes and loads configuration settings from SPIFFS.
 *
 * This function is designed to initialize the SPIFFS file system and load configuration settings
 * from a JSON file stored on the device. It reads the 'config.json' file from SPIFFS, parses its
 * content to extract configuration parameters like Google Script ID, Sheet Name, Document ID, host,
 * and HTTPS port. The function updates these parameters into the global
 * configuration structure if the file exists and is successfully parsed.
 *
 * @note If 'config.json' does not exist or the SPIFFS cannot be initialized, the configuration will
 *       not be updated, and the device will use default settings or previously loaded
 * configurations.
 *
 * @pre SPIFFS must be properly set up in the platform's filesystem before calling this function.
 *
 * @post On successful execution, the global configuration structure is updated with values loaded
 *       from 'config.json'. Custom fields are also updated to reflect these new configurations.
 *
 * @see updateCustomFields()
 *
 * Usage Example:
 *
 * Assuming 'config.json' is properly formatted and stored, calling this function at startup
 * helps in initializing device settings without hard-coding them into the firmware.
 */
void setupConfig() {
  display.printf("Setting up config\n");
  display.display();
  Serial.println("setupConfig: Initializing SPIFFS");
  if (SPIFFS.begin(true)) {
    Serial.println("setupConfig: Checking if config exists");
    if (SPIFFS.exists("/config.json")) {
      Serial.println("setupConfig: Opening config");
      File configFile = SPIFFS.open("/config.json", "r");
      if (configFile) {
        Serial.println("setupConfig: Loading content");
        size_t size = configFile.size();
        std::unique_ptr<char[]> buf(new char[size]);
        configFile.readBytes(buf.get(), size);
        configFile.close();
        Serial.println("setupConfig: Parsing json:");
        Serial.println(buf.get());
        json.clear();
        deserializeJson(json, buf.get());
        conf.GScriptId = jsonValueOrDefault(json, "gscript_id");
        conf.SheetName = jsonValueOrDefault(json, "sheet_name", "distance");
        conf.DocumentID = jsonValueOrDefault(json, "document");
        conf.host = jsonValueOrDefault(json, "host", "script.google.com");
        conf.httpsPort = jsonValueOrDefault(json, "httpsPort", "443");
        conf.cert = jsonValueOrDefault(json, "certificate", root_ca);

        json.clear();
        updateCustomFields();  // Update custom fields to reflect new configurations
      }
    } else {
      Serial.println("setupConfig: Config file not found");
    }
  } else {
    Serial.println("setupConfig: Failed to initialize SPIFFS");
    display.println("SPIFFS init failed. Halting");
    display.display();
    while(true){delay(1000);}
  }
}

/**
 * Print initial status on the OLED display.
 */
void printInitialDisplay() {
  display.clearDisplay();
  display.setCursor(0, 0);
  display.print("System Initialized");
  display.display();
}

/**
 * @brief Initializes the OLED display.
 *
 * This function is responsible for setting up the OLED display using the Adafruit SSD1306 library.
 * It starts by resetting the display, then attempts to initialize it with specified configuration
 * parameters. If the initialization fails, the function halts the program execution and prints
 * an error message to the serial monitor.
 *
 * @note This function will enter an infinite loop if the OLED display fails to initialize.
 *       Check the display connections and configurations if this occurs.
 *
 * @pre OLED_RST must be connected to a valid GPIO pin configured as an output.
 *
 * @post If the function returns (does not halt), the OLED display is ready for use.
 */
void setupDisplay() {
  
  // Attempt to initialize the OLED display
  if (!display.begin(SSD1306_SWITCHCAPVCC, SCREEN_ADDRESS)) {
    Serial.println("OLED initialization failed");  // Initialization failed message
    for (;;)
      ;  // Halt execution on failure
  }
  display.setTextSize(1);             // Normal 1:1 pixel scale
  display.setTextColor(SSD1306_WHITE);        // Draw white text
  display.clearDisplay();
  display.setCursor(0, 0);
  display.printf("Initializing \n");
  display.display();
}
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

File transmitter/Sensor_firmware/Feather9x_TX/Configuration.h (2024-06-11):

/**
 * @file Configuration.h
 * @author Sebastien Leclerc 
 * @brief This program is used to take measurements (including one of a distance sensor )
 *        and transmit it using a Lora Radio
 * @version 0.1
 * @date 2024-06-04
 * 
 * @copyright Copyright (c) 2024
 *
 * MIT License
 * 
 * Copyright (c) 2024 Sebastien Leclerc
 * 
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
 * THE SOFTWARE IS PROVIDED "AS IS", WITHOUT WARRANTY OF ANY KIND, EXPRESS OR
 * IMPLIED, INCLUDING BUT NOT LIMITED TO THE WARRANTIES OF MERCHANTABILITY,
 * FITNESS FOR A PARTICULAR PURPOSE AND NONINFRINGEMENT. IN NO EVENT SHALL THE
 * AUTHORS OR COPYRIGHT HOLDERS BE LIABLE FOR ANY CLAIM, DAMAGES OR OTHER
 * LIABILITY, WHETHER IN AN ACTION OF CONTRACT, TORT OR OTHERWISE, ARISING FROM,
 * OUT OF OR IN CONNECTION WITH THE SOFTWARE OR THE USE OR OTHER DEALINGS IN THE
 * SOFTWARE.
 ***/
#pragma once

// uncomment to enable serial debug output. This also sets the sleep time to 
// SLEEP_TIME_DEBUGGIG which should in theory be smaller than the non-debugging
// sleep time in the field
// #define SERIAL_OFF

// sleep time when SERIAL_OFF is commented out for debugging 
#define SLEEP_TIME_DEBUGGING_SEC 30


// Sleep time when battery level is sufficient to wake up and
// take measurements
#define SLEEP_TIME_REGULAR_SECONDS 15*60



#ifdef DEEP_SLEEP_ENABLE
#define SLEEP_TIME_SEC SLEEP_TIME_REGULAR_SECONDS
#else
#define SLEEP_TIME_SEC SLEEP_TIME_DEBUGGING_SEC
#endif


// Sleep time when battery level is below threshold
#define SLEEP_TIME_LOW_POWER_MS 20000
#define VOLTAGE_MIN_THRESHOLD 2.7

// Delay between each voltage reads 
#define VOLTAGE_READ_DELAY_MS 500

// Change to 440.0 or other frequency, must match RX's freq!
// #define RF95_FREQ 915.0
#define RF95_FREQ 433.0
// Bw125Cr48Sf4096 has slow burst but long range
#define RF95_MODE RH_RF95::Bw125Cr48Sf4096


// Sleep delay multiplier on BOD 
#define BOD33_SLEEP_MULTIPLIER 10



// RF95 registers

#define RH_RF95_REG_40_DIO_0_pos 6
#define RH_RF95_REG_40_DIO_1_pos 4
#define RH_RF95_REG_40_DIO_2_pos 2
#define RH_RF95_REG_40_DIO_3_pos 0
#define RH_RF95_REG_41_DIO_4_pos 6
#define RH_RF95_REG_41_DIO_5_pos 4

#define RH_RF95_REG_40_DIO_0_RXDONE 0b00
#define RH_RF95_REG_40_DIO_1_RXTIMEOUT 0b00
#define RH_RF95_REG_40_DIO_2_FhssChangeChannel_1 0b00
#define RH_RF95_REG_40_DIO_3_CadDone 0b00
#define RH_RF95_REG_41_DIO_4_CadDetected 0b00
#define RH_RF95_REG_41_DIO_5_ModeReady 0b00

#define RH_RF95_REG_40_DIO_0_TXDONE 0b01
#define RH_RF95_REG_40_DIO_1_FhssChangeChannel 0b01
#define RH_RF95_REG_40_DIO_2_FhssChangeChannel_2 0b01
#define RH_RF95_REG_40_DIO_3_ValidHeader 0b01
#define RH_RF95_REG_41_DIO_4_PllLock 0b01
#define RH_RF95_REG_41_DIO_5_ClkOut 0b01

#define RH_RF95_REG_40_DIO_0_CADDONE 0b10
#define RH_RF95_REG_40_DIO_1_CadDetected 0b10
#define RH_RF95_REG_40_DIO_2_FhssChangeChannel_3 0b10
#define RH_RF95_REG_40_DIO_3_PayloadCrcError 0b10
#define RH_RF95_REG_41_DIO_4_PllLock2 0b10
#define RH_RF95_REG_41_DIO_5_ClkOut2 0b10

#define RH_RF95_REG_40_DIO_0_DISABLE 0b11
#define RH_RF95_REG_40_DIO_1_DISABLE 0b11
#define RH_RF95_REG_40_DIO_2_DISABLE 0b11
#define RH_RF95_REG_40_DIO_3_DISABLE 0b11
#define RH_RF95_REG_41_DIO_4_DISABLE 0b11
#define RH_RF95_REG_41_DIO_5_DISABLE 0b11

#define RH_RF95_REG_40_DIO_0(val) (val << RH_RF95_REG_40_DIO_0_pos)
#define RH_RF95_REG_40_DIO_1(val) (val << RH_RF95_REG_40_DIO_1_pos)
#define RH_RF95_REG_40_DIO_2(val) (val << RH_RF95_REG_40_DIO_2_pos)
#define RH_RF95_REG_40_DIO_3(val) (val << RH_RF95_REG_40_DIO_3_pos)
#define RH_RF95_REG_41_DIO_4(val) (val << RH_RF95_REG_41_DIO_4_pos)
#define RH_RF95_REG_41_DIO_5(val) (val << RH_RF95_REG_41_DIO_5_pos)



// Define the address in SRAM for triple-tap detection
#define SCALE_ADDRESS                0
#define WRITTEN_SIGNATURE            0xBEEFDEED
#define DISTANCE_FROM_PULSE_MM(pulse_width,scale_us_per_cm) ((uint32_t)((double)pulse_width / scale_us_per_cm) * 10)
#define BOOT_WAIT_FOR_SERIAL_MS      2000

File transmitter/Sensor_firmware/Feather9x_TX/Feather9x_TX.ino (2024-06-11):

/**
 * @file Feather9x_TX.ino
 * @author Sebastien Leclerc 
 * @brief This program is used to take measurements (including one of a distance sensor )
 *        and transmit it using a Lora Radio
 * @version 0.1
 * @date 2024-06-04
 * 
 * @copyright Copyright (c) 2024
 *
 * MIT License
 * 
 * Copyright (c) 2024 Sebastien Leclerc
 * 
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
 * THE SOFTWARE IS PROVIDED "AS IS", WITHOUT WARRANTY OF ANY KIND, EXPRESS OR
 * IMPLIED, INCLUDING BUT NOT LIMITED TO THE WARRANTIES OF MERCHANTABILITY,
 * FITNESS FOR A PARTICULAR PURPOSE AND NONINFRINGEMENT. IN NO EVENT SHALL THE
 * AUTHORS OR COPYRIGHT HOLDERS BE LIABLE FOR ANY CLAIM, DAMAGES OR OTHER
 * LIABILITY, WHETHER IN AN ACTION OF CONTRACT, TORT OR OTHERWISE, ARISING FROM,
 * OUT OF OR IN CONNECTION WITH THE SOFTWARE OR THE USE OR OTHER DEALINGS IN THE
 * SOFTWARE.
 ***/


/*
 * Prerequisite libraries to be installed:
 *   Arduino Low Power by Adruino, >= v1.2.2 
 *   RadioHead  by Mike McCauley, >= v1.122.1 
 *   Internal Temperature Zero Library by Electronic Cats, >=1.2.0
 * 
 * Board manager:
 *   Adafruit Feather M0 (SAMD21) 
 *
 * Review the settings in the "Configuration.h" file and make sure that the 
 * radio settings (frequency, modulation, etc) match with the receiver module's
 * compile definitions.
 *
 * This version is a work in progress, including several portions used for troubleshooting
 * as well as debugging with the objective of reducing the power usage to the minimum achievable
 * by the electronics of the board. 
 * 
 *
 * Uploading:
 *   By default, the usb serial device used for uploading the code is disabled and the Arduino
 * IDE cannot flash binaries. The bootloader used in this project requires double-pressing
 * the button on the board to enable the upload port.
 * 
 **/

#include "ArduinoLowPower.h"
#include "Configuration.h"
#include "Definitions.h"
#include <RH_RF95.h>
#include <SPI.h>
#include <LoraEncoder.h>
#include <FlashStorage_SAMD.h>
#include <TemperatureZero.h>

globals_t ctx = { { 0, 0, 0.0f, 0, 0.0f, 0.0f, 0, 0 }, false, 0, false, false, BOD33_SLEEP_MULTIPLIER };

// Singleton instance of the radio driver
RH_RF95 rf95(RFM95_CS, RFM95_INT);
TemperatureZero TempZero = TemperatureZero();


// Define your reference voltage array
float vref[] = {
  3.3f,   // AR_DEFAULT
  1.0f,   // AR_INTERNAL1V0
  1.1f,   // AR_INTERNAL1V1
  1.2f,   // AR_INTERNAL1V2
  1.25f,  // AR_INTERNAL1V25
  2.0f,   // AR_INTERNAL2V0
  2.2f,   // AR_INTERNAL2V2
  2.23f,  // AR_INTERNAL2V23
  2.4f,   // AR_INTERNAL2V4
  2.5f,   // AR_INTERNAL2V5
  1.65f,  // AR_INTERNAL1V65
  -1.0f   // AR_EXTERNAL Placeholder (you need to set this based on your external Vref)
};

void read_vbat() {

  // if (ctx.next_volt_read < millis()) {
  Serial.println("Read VBAT");
  // throttle voltage reading

  pinMode(VBAT_PIN, INPUT);
  pinMode(RS485_POWER, OUTPUT);     // Set RS485_POWER pin as digital input
  digitalWrite(RS485_POWER, HIGH);  // put TMP36 chip on
  wait_ms(100);

  // #ifndef SERIAL_OFF
  analogReference(AR_DEFAULT);
  ctx.measures.bat_voltage = (float)analogRead(VBAT_PIN) * 2.0f * 3.3f / 1024;
  Serial.print("VBAT: ");
  Serial.println(ctx.measures.bat_voltage, 3);
  digitalWrite(RS485_POWER, LOW);


  // #endif

  //  todo: fix under power
  //          if (ctx.measures.bat_voltage < VOLTAGE_MIN_THRESHOLD) {
  //              ctx.insufficient_power = true;
  //              flash_D3(2, 200, 100);
  //      Serial.println("Insufficient voltage detected");

  //         } else {
  //     Serial.println("Sufficient voltage detected");
  //             ctx.insufficient_power = false;
  //             flash_D3(3, 200, 100);
  //         }
  //     ctx.next_volt_read = millis() + VOLTAGE_READ_DELAY_MS;
  // }
}
uint64_t readUniqueID64() {
  uint32_t* uid = (uint32_t*)0x0080A00C;
  return ((uint64_t)uid[0] << 32) | uid[1];
}

// void setupADC() {
// #ifdef SERIAL_OFF
//   adcTemperature.enable(
//     GCLKGEN_ID_ADC_1MHz, GCLKGEN_ID_ADC_1MHz_FREQ, Analog2DigitalConverter::DIV4);
//   adcTemperature.setReference(Analog2DigitalConverter::Reference::REF_INTVCC_DIV_2, 1.65, false);
//   adcTemperature.setGain(Analog2DigitalConverter::Gain::GAIN_DIV2);
//   adcTemperature.setSampling(0, 3);
//   adcVoltage.enable(GCLKGEN_ID_ADC_1MHz, GCLKGEN_ID_ADC_1MHz_FREQ, Analog2DigitalConverter::DIV4);
//   adcVoltage.setReference(Analog2DigitalConverter::Reference::REF_INTVCC_DIV_2, 3.3);
//   adcVoltage.setGain(Analog2DigitalConverter::Gain::GAIN_DIV2);
//   adcVoltage.setSampling(0, 3);
//   adcInternalTemp.enable(
//     GCLKGEN_ID_ADC_1MHz, GCLKGEN_ID_ADC_1MHz_FREQ, Analog2DigitalConverter::DIV4);
//   // configure continuous hardware averaging (2^3 = 8)
//   adcInternalTemp.setSampling(0, 3);
//   // disable ADC to save power until start of conversion
//   adcInternalTemp.disable();
//   adcInternalVoltage.enable(
//     GCLKGEN_ID_ADC_1MHz, GCLKGEN_ID_ADC_1MHz_FREQ, Analog2DigitalConverter::DIV4);
//   // configure continuous hardware averaging (2^3 = 8)
//   adcInternalVoltage.setSampling(0, 3);
//   // disable ADC to save power until start of conversion
//   adcInternalVoltage.disable();

//   // disable to save power until we are ready
//   adcVoltage.disable();
//   adcTemperature.disable();

// #endif
// }

void wait_ms(uint32_t ms) {
#ifdef DEEP_SLEEP_ENABLE
  LowPower.idle(ms);
#else
  delay(ms);
#endif

  // Serial.println("Done delay");
}
void setUsPerCM(double scale) {
  // Save into emulated-EEPROM the number increased by 1 for the next run of the sketch
  Serial.print("Storing scale (us/cm): ");
  Serial.println(scale);
  EEPROM.put(SCALE_ADDRESS, WRITTEN_SIGNATURE);
  EEPROM.put(SCALE_ADDRESS + sizeof(WRITTEN_SIGNATURE), scale);
  if (!EEPROM.getCommitASAP()) {
    Serial.println("CommitASAP not set. Need commit()");
    EEPROM.commit();
  }
}

double getUsPerCM() {
  int signature;
  double result = PULSE_SCALE_MS_PER_CM;
  EEPROM.get(SCALE_ADDRESS, signature);
  if (signature != WRITTEN_SIGNATURE) {
    Serial.println("EEPROM is empty, Setting default");
    setUsPerCM(PULSE_SCALE_MS_PER_CM);
  } else {
    EEPROM.get(SCALE_ADDRESS + sizeof(WRITTEN_SIGNATURE), result);
  }
  return result;
}


void checkReset() {
  unsigned long startTime = millis();
  pinMode(JP1, INPUT_PULLUP);
  Serial.print("JP1: ");
  Serial.println(digitalRead(JP1) == HIGH ? "OFF" : "ON");
  while (digitalRead(JP1) == LOW) {    // Wait while the pin is held low
    if (millis() - startTime > 500) {  // Check if the pin is low for more than 500ms
      Serial.println("JP1 held low for 500ms, resetting scale value.");
      setUsPerCM(-1);
      break;
    }
  }
}
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
